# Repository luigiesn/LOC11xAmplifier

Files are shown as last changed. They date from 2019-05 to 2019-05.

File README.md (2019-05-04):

# LOC11xAmplifier
An optically insulated amplifier with 4x gain / Um amplificador isolado opticamente com ganho de 4x

O amplificador é baseado no optoacoplador linear [LOC110S/P](circuit/kicadlib/datasheet/LOC110.pdf) e foi projetado a fim de testar a técnica de se utilizar um par óptico casado de fotodiodos para fazer um circuito isolado e realimentado simultâneamente.

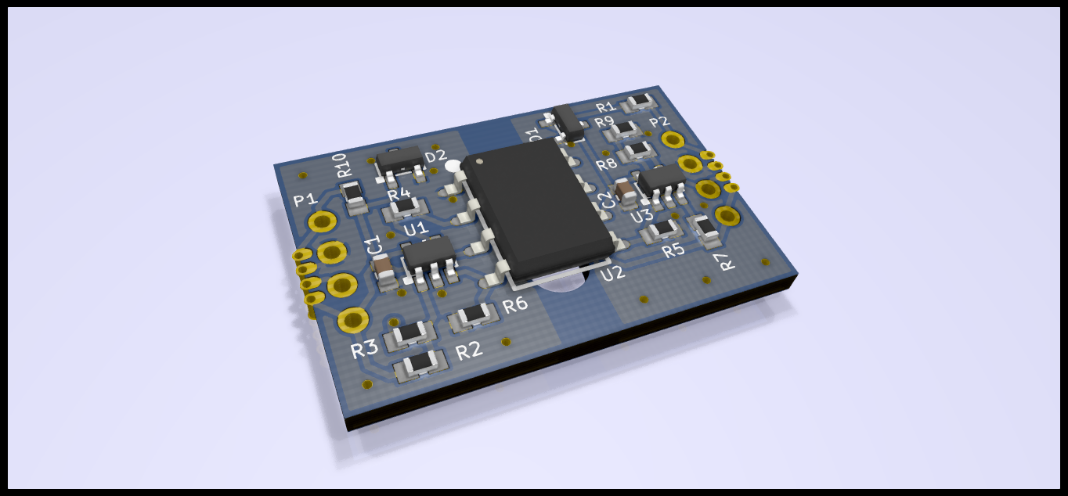
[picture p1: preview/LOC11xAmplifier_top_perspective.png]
Visualização 3D da face superior da placa


O projeto foi feito agora precisa ser testado :)

## Especificações

### Condições de Operação Recomendadas¹

| Parâmetro | Condições | Símbolo | Mín. |Típico | Máx. | Unidade |
| :--- | :---: | :---: | :---: | :---: | :---: | :---: |
| **Alimentação** |
| Tensão de Alimentação do Estágio de Entrada | - | Vs_1 | 3.15 | - | 3.75 | V |
| Tensão de Alimentação do Estágio de Saída | - | Vs_2 | 3.02 | - | 4.36 | V |
| Corrente Quiescente do Estágio de Entrada | Vs_1 = 3.3 V, V_in = 0 | I_q1 | - | 6.98 | - | mA |
| Corrente Quiescente do Estágio de Saída | Vs_2 = 3.3 V, V_in = 0 | I_q2 | - | 3.3 | - | mA |
| **Amplificador** |
| Tensão de Entrada | - | V_in | -250 | - | 250 | mV |
| Impedância de Entrada |  - | Z_in | - | 60.44 | - | kΩ |
| Tensão de _Offset_ de Saída | - | V_off | - | 1.535 | - | V |
| Corrente Máxima de Saída | Vs_2 = 3.15 V |  | - | - | 1.5 |  |
| | Vs_2 = 3.3 V | I_o | - | - | 3.1 | mA |
| | Vs_2 = 3.5 V | | - | - | 5.3 |  |
| Ganho de Tensão |  - | A_v | - | 3.98 | - |  |
| Resposta de frequência² | - | f_-3db | - | 200 | - | kHz
###### ¹ valores calculados para 25°C
###### ² valor com referência no modo de operação fotocondutiva dos fotodiodos

## O circuito

Os componentes e topologias do circuito foram escolhidos a fim de obter baixo custo, mas com especificações razoáveis. Suas conexões estão disponíveis para barras de pinos de 2.54 mm de espaçamento e pads nas bordas para uma soldagem SMT

O circuito opera nominalmente com tensões de alimentação de 3.3 V, faixas de entrada de ±250 mV e tensão de saída centralizada em 1.535 V e ganho de 3.98 do sinal de entrada.

Em função da configuração fotocondutiva dos [pares ópticos](circuit/kicadlib/datasheet/LOC110.pdf), o circuito opera até 200 kHz. 

#### Operação

O estágio de entrada foi projetado para operar na faixa de 2.5 até 3.5 mA do diodo emissor. Essa região foi escolhida por resultar em uma baixa variação de ganho do sinal em 25 °C. 

Seus [amplificadores](circuit/kicadlib/datasheet/tlv9001.pdf) são _rail-to-rail_ para entradas e saída com baixo _offset_ de entrada e baixo consumo (1 μA)

As [referências de tensão](circuit/kicadlib/datasheet/lm4040-n.pdf) são de 2 % do tipo _shunt_

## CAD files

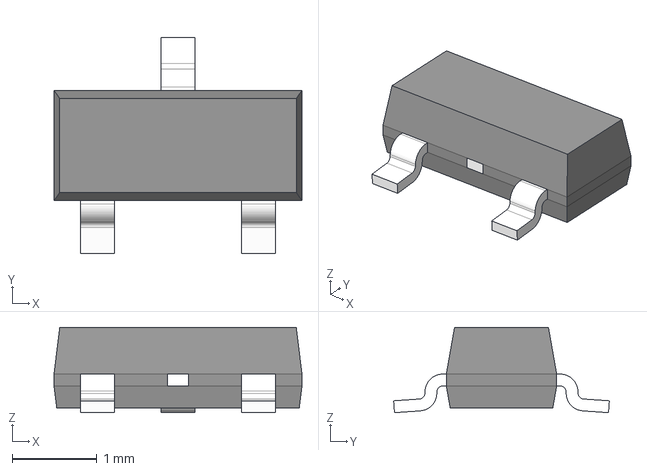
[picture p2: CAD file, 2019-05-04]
circuit/kicadlib/3d/SOT23-3.step
2.92 x 2.54 x 1.01 mm

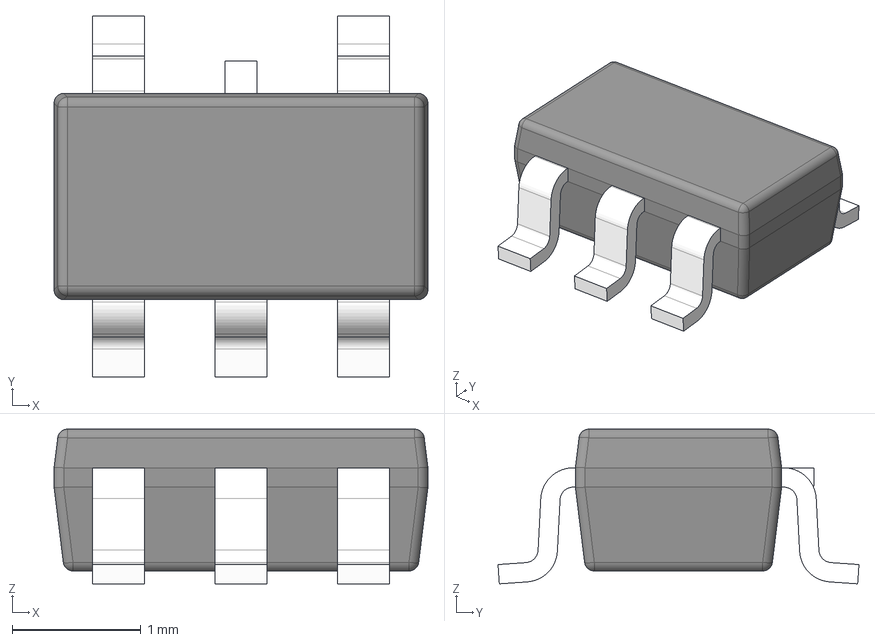
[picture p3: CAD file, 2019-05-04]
circuit/kicadlib/3d/SOT-23-5.step
2.90 x 2.80 x 1.20 mm

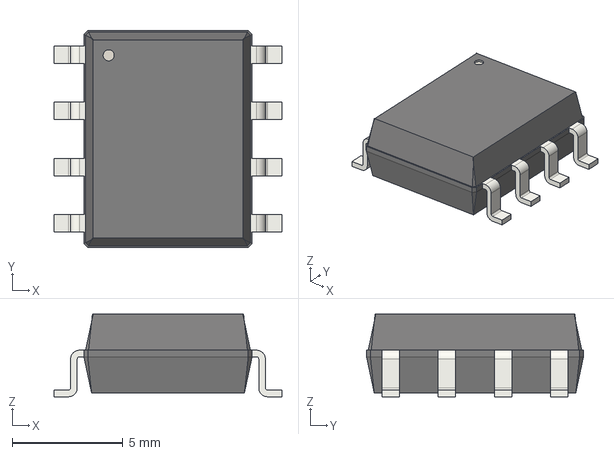
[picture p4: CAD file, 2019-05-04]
circuit/kicadlib/3d/SSO_8.step
10.3 x 9.80 x 3.73 mm

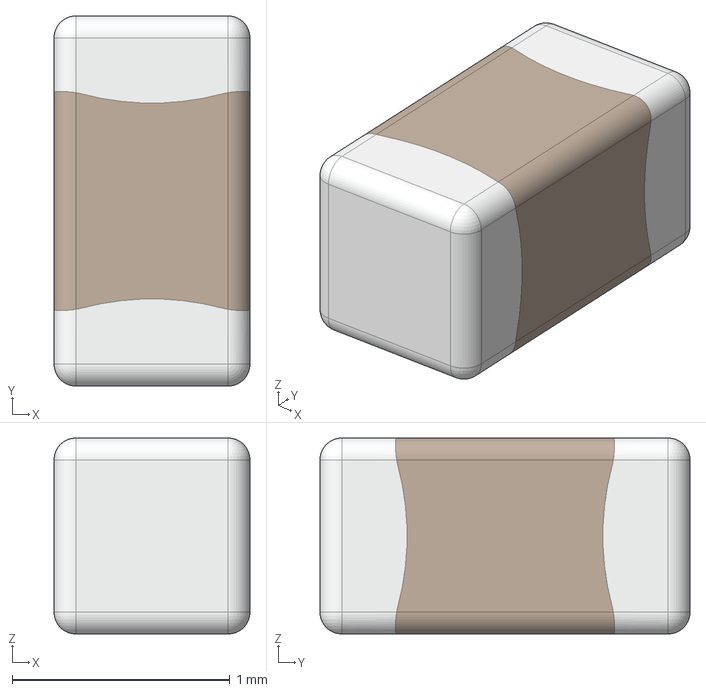
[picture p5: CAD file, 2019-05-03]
circuit/kicadlib/3d/CAP_0603.step
0.9 x 1.70 x 0.9 mm

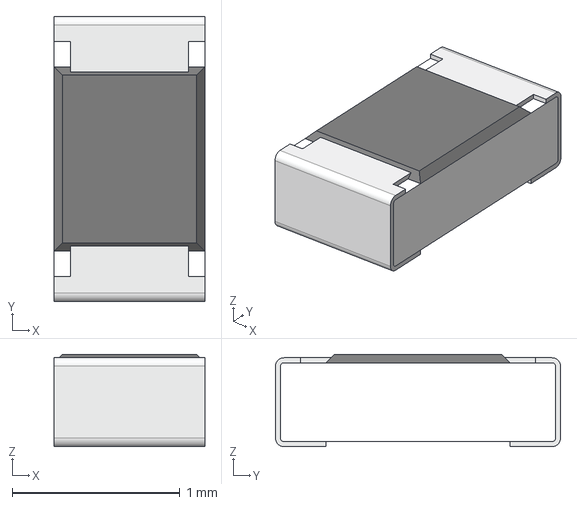
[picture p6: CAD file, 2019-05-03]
circuit/kicadlib/3d/RES_0603.step
0.9 x 1.70 x 0.55 mm

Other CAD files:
circuit/kicadlib/3d/SOT23-3.stp

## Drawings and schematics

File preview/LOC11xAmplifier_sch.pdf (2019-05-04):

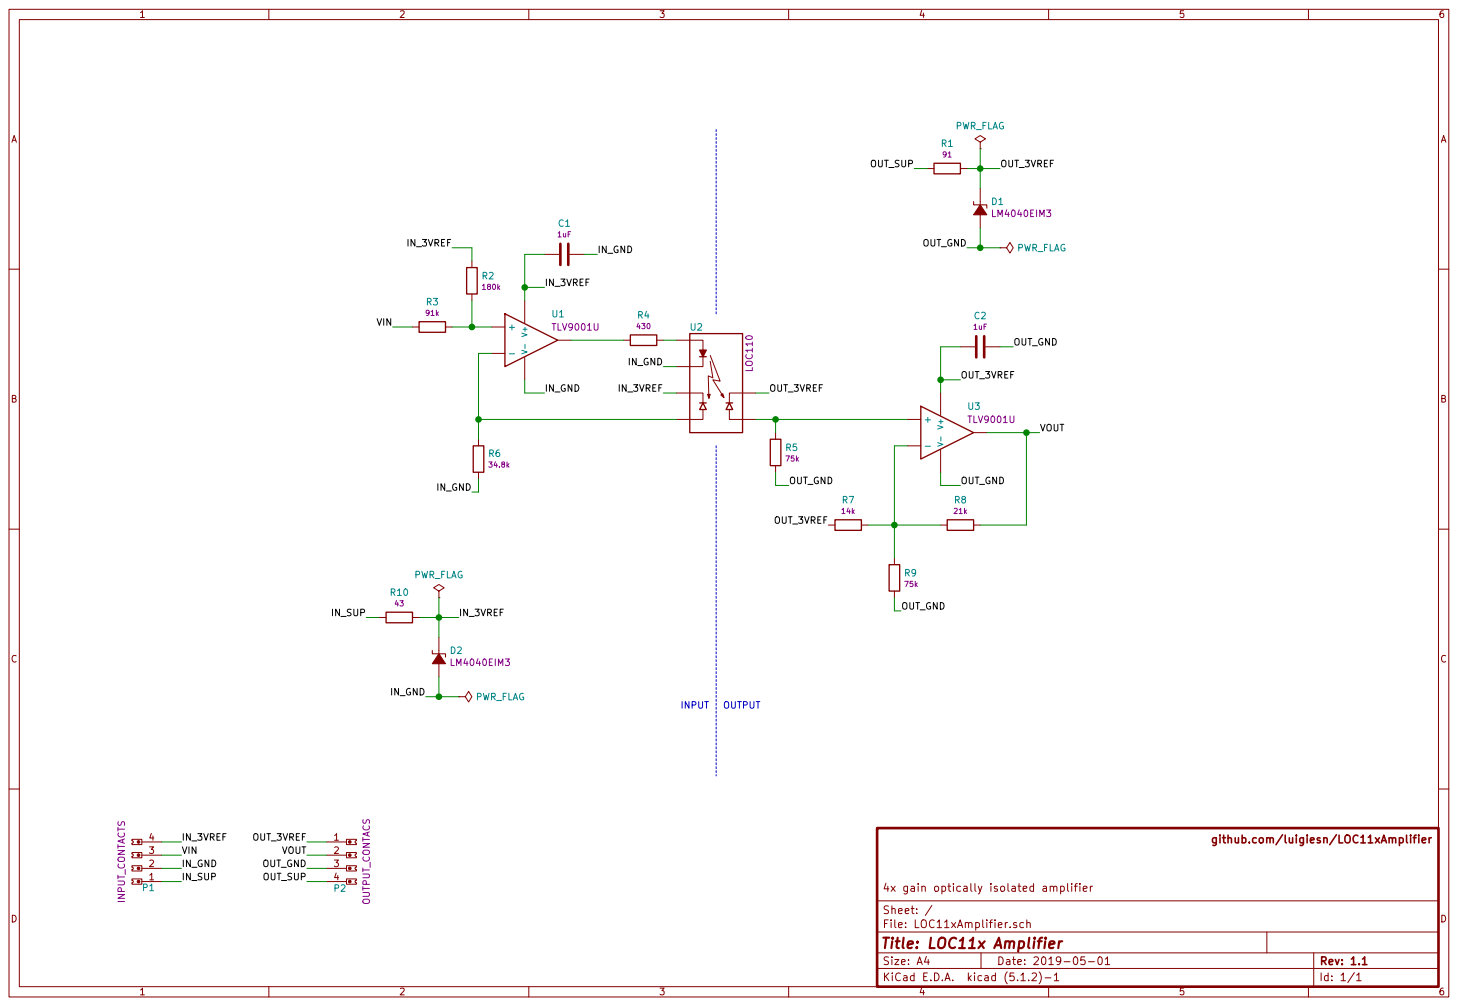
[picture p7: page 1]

4x gain optically isolated amplifier

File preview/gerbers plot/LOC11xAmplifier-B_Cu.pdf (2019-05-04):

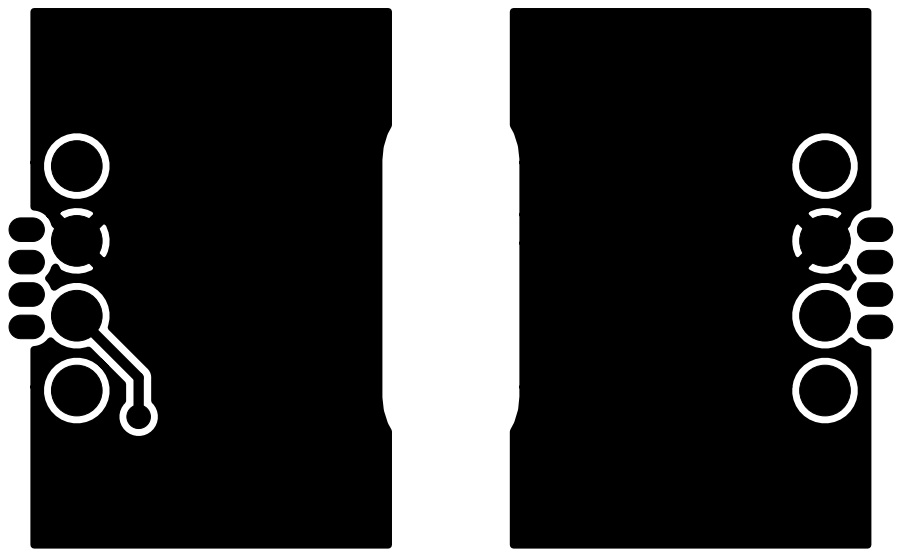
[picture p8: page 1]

4x gain optically isolated amplifier

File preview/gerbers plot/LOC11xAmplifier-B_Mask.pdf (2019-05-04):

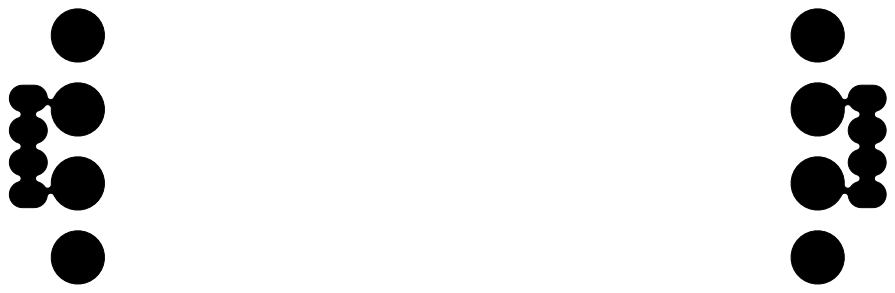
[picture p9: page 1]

4x gain optically isolated amplifier

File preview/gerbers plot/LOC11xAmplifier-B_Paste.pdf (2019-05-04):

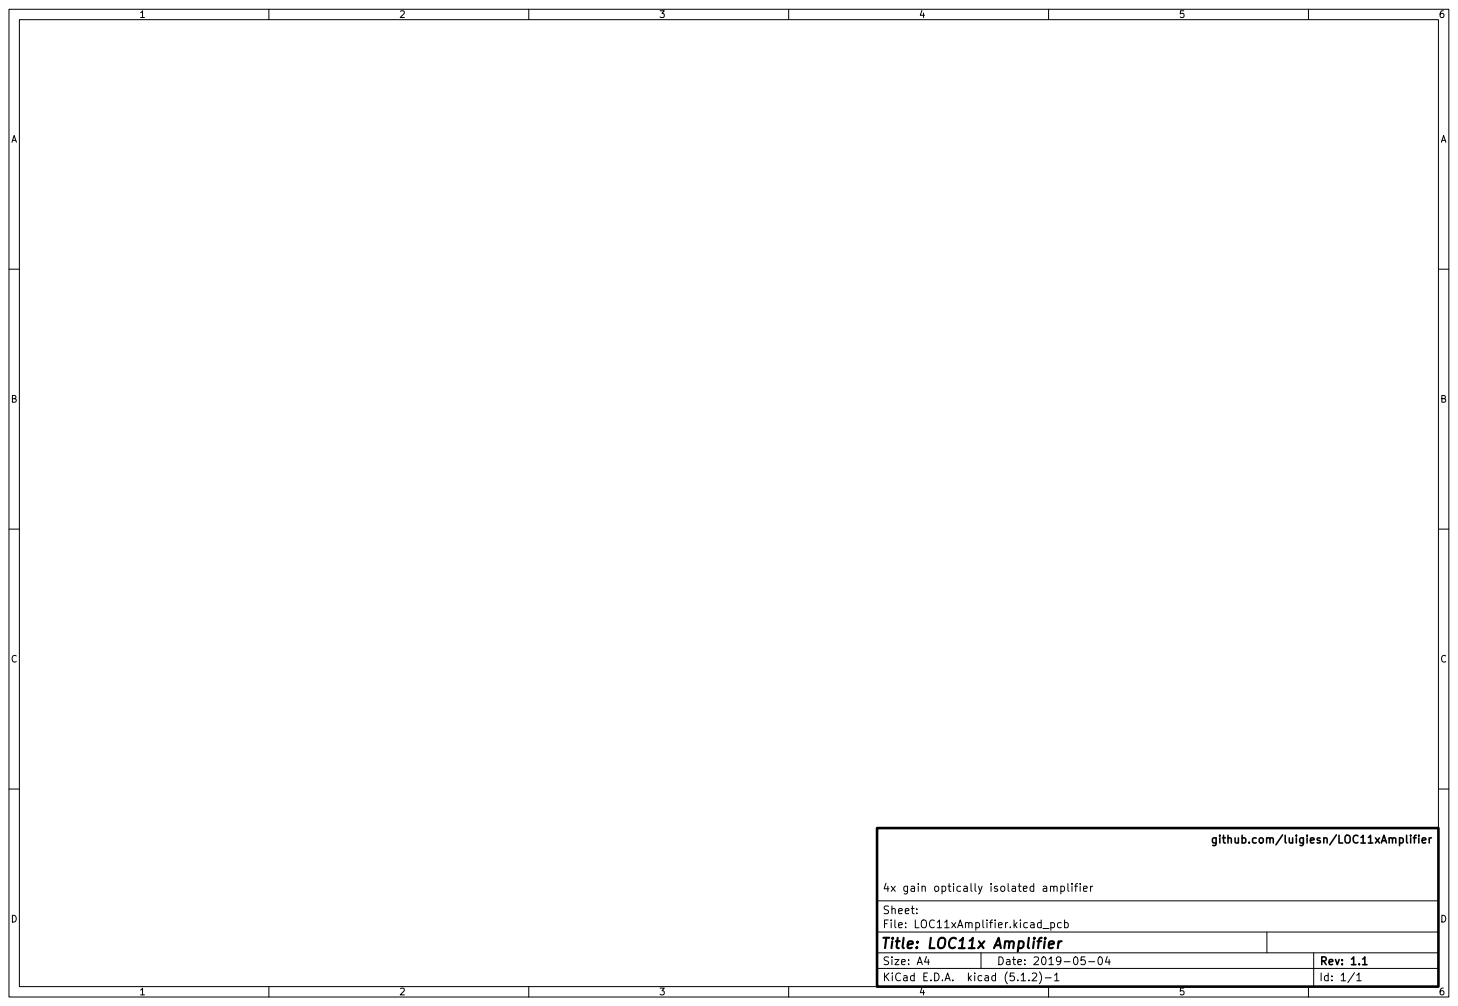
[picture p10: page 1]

4x gain optically isolated amplifier

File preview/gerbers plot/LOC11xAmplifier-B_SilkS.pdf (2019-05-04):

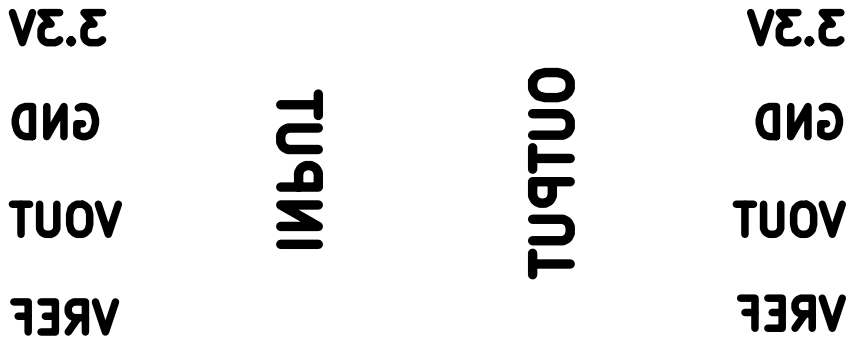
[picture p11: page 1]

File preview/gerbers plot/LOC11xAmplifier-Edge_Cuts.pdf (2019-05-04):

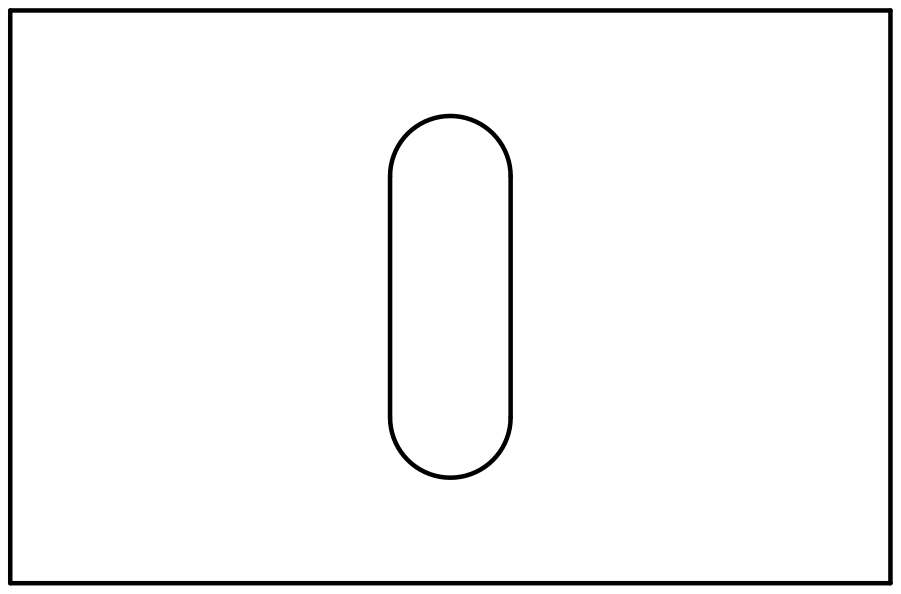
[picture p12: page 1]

4x gain optically isolated amplifier

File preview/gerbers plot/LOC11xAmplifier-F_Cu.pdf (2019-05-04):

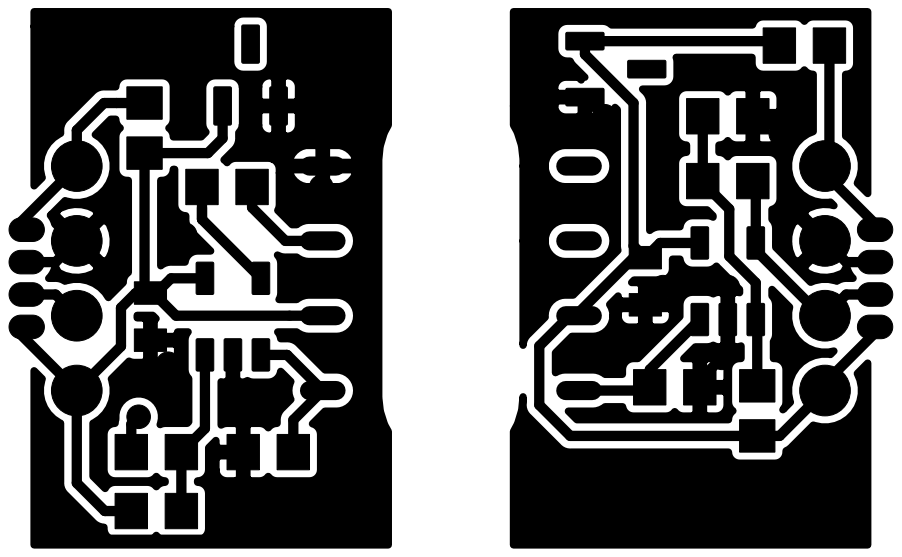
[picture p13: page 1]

4x gain optically isolated amplifier

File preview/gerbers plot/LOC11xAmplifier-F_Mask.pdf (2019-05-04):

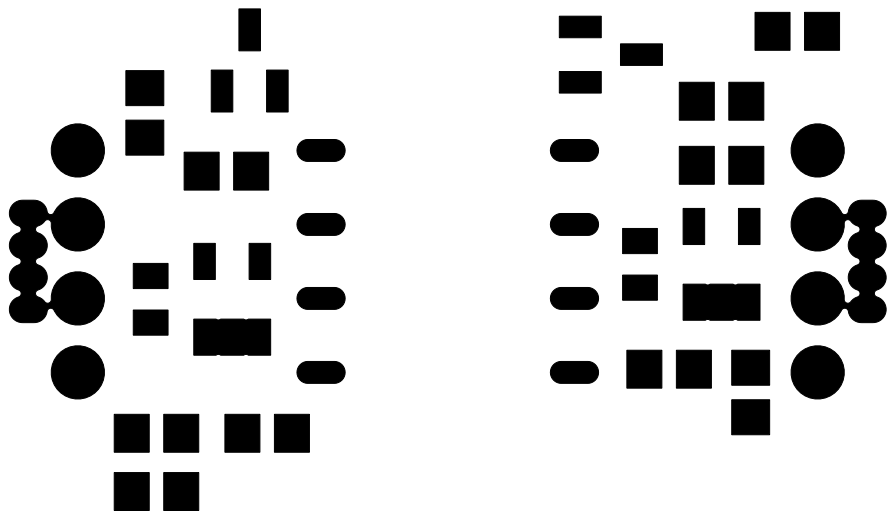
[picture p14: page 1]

4x gain optically isolated amplifier

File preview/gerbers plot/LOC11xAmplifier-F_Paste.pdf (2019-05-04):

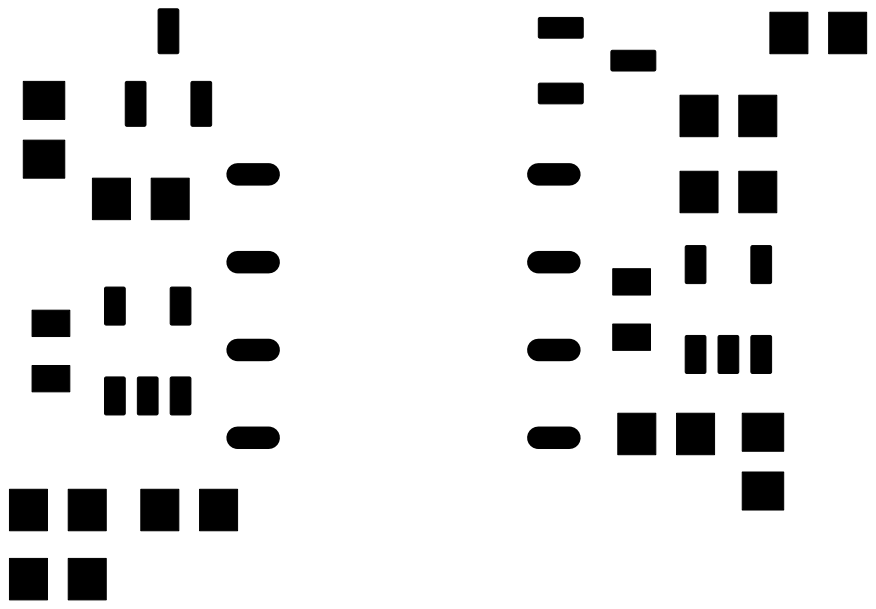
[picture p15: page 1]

4x gain optically isolated amplifier

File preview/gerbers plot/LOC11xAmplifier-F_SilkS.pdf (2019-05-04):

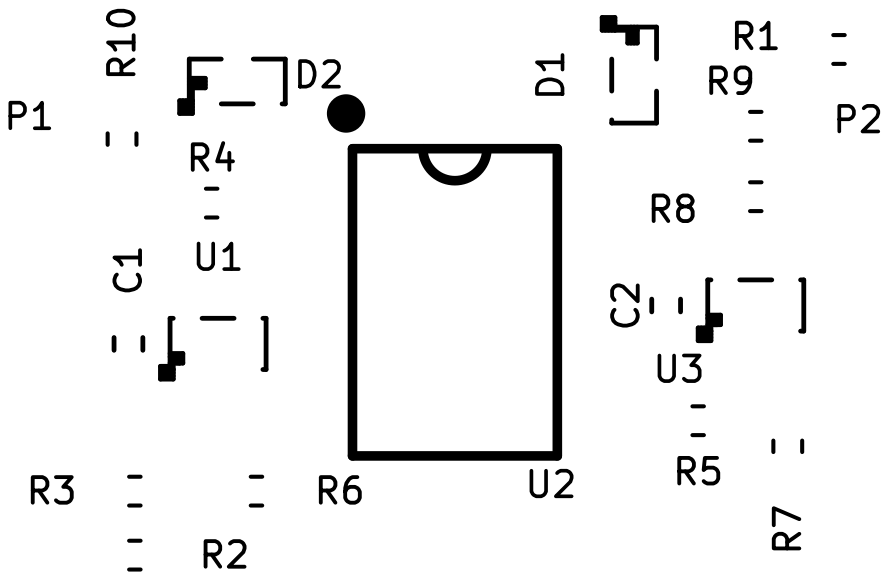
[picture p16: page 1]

4x gain optically isolated amplifier

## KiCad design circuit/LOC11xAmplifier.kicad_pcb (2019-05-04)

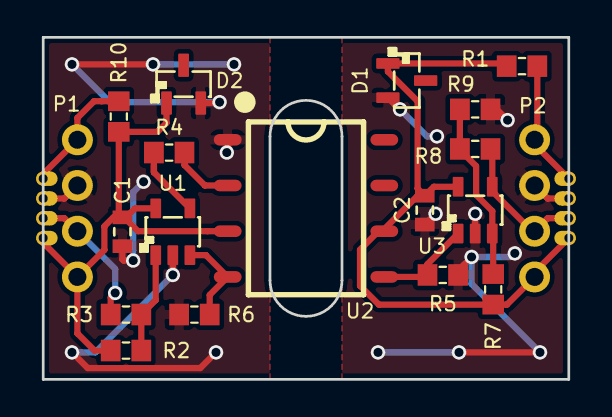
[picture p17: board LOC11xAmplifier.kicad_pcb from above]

Board: 2 copper layers, 29.2 x 19.0 mm, 19 parts (0 on the bottom side), 14 nets.

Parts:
C1, C2: CC0603MRY5V6BB105; CAP_0603
D1, D2: LM4040EIM3X-3.0_NOPB; SOT23-3_LM4040N
P1, P2: 4P_PLATING1.1MM_HOLE2.54MM
R1: RC0603FR-0791RL; RES_0603
R2: RC0603FR-07180KL; RES_0603
R3: RC0603FR-0791KL; RES_0603
R4: RC0603FR-07430RL; RES_0603
R5, R9: RC0603FR-0775KL; RES_0603
R6: RC0603FR-0734K8L; RES_0603
R7: RC0603FR-0714KL; RES_0603
R8: RC0603FR-0721KL; RES_0603
R10: RC0603FR-0743RL; RES_0603
U1, U3: TLV9001UIDBVR; SOT23-5_TLV9001
U2: LOC110PTR; SO8_LOC110P

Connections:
/IN_3VREF: C1.2, D2.1, P1.4, R2.1, R10.1, U1.5, U2.3
/IN_GND: C1.1, D2.2, P1.2, R6.1, U1.2, U2.1
/IN_SUP: P1.1, R10.2
/OUT_3VREF: C2.2, D1.1, P2.1, R1.1, R7.2, U2.6, U3.5
/OUT_GND: C2.1, D1.2, P2.3, R5.2, R9.2, U3.2
/OUT_SUP: P2.4, R1.2
/VIN: P1.3, R3.2
/VOUT: P2.2, R8.1, U3.4
unnamed: R2.2, R3.1, U1.1
unnamed: R4.1, U2.2
unnamed: R4.2, U1.4
unnamed: R5.1, U2.5, U3.1
unnamed: R6.2, U1.3, U2.4
unnamed: R7.1, R8.2, R9.1, U3.3

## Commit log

2019-05-03 Primeiro commit
    Primeira versão do amplificador. Inclusão de:
    - datasheets
    - bibliotecas
    - esquemático e layout
    [CAP_0603.step, LOC11xAmplifier.kicad_pcb, LOC11xAmplifier.sch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]
2019-05-03 Inclusão de arquivos de pré-visualização
    Disponibilização de imagens em perpectiva da placa e esquemático em .pdf
2019-05-03 Inclusão de resistor
    RC0603FR-0743RL incluído na biblioteca
    [LOC11xAmplifier.kicad_pcb, LOC11xAmplifier.sch]
2019-05-03 Adicionada descrição do circuito
    Adicionada especificações e detalhes de operação do circuito
2019-05-04 Atualizando o esquemático em pdf
    Alterado resistor R10 de 91ohms para 43ohms
2019-05-04 Alterado o esquemático
    - Atualizada versão do esquemático para v1.1
    - Incluido endereço do repositório
    - Alterado layout da worksheet
    [LOC11xAmplifier.sch]
2019-05-04 Atualizado o esquemático .pdf
    - Atualizado para a v1.1
2019-05-04 Alterado rodapé
    - aplicado novo worksheet
    - adicionada descrição no rodopé
    [LOC11xAmplifier.kicad_pcb]
2019-05-04 Incluídos 3D na biblioteca
    Incluídos? SSO8, SOT23-3 e SOT23-5
    [SOT-23-5.step, SOT23-3.step, SOT23-3.stp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]
2019-05-04 Incluídos 3Ds nos footprints
    SO8_LOC110P, SOT23-3_LM4040N e SOT23-5_TLV9001
2019-05-04 Atualizado layout
    Atualizados footprints com 3D
    [LOC11xAmplifier.kicad_pcb]
2019-05-04 Nova renderização
    Atualização dos footprints e aplicado raytracing
2019-05-04 Adicionados prints dos gerbers
